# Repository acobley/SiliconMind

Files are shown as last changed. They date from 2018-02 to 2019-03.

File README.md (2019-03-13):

View this project on [CADLAB.io](https://cadlab.io/node/794). 

# SiliconMind
PCB3 is a test release.  
**Do not use** . Unwired airwire on PCB.
Use the hardware files

Pure Keys aec-pcb3.sch
Pure Keys aec-pcb3.brd

PCB2 is a working release.  Use the hardware files

Pure Keys aec-pcb2.sch
Pure Keys aec-pcb2.brd

**make sure that the 20 way header(keyboard connector) is soldered on so the connector is on the otherside of the board to the components. **

**Button 1** controls the mode. Starts in Polyphonc mode.  
Press once (2 flashes) for split mode.  CV1/Trig1 is lower half of keyboard. CV2/Trig2 is upper
Press again (3 flashes for mono mode.  CV1/Trig 1 only
Press again (1 flash) to return to poly mode.

**Button 2* is record/play mode
Press and hold (button flashes when ready) to enter record mode.  The note on each trig in will be recorded (up to 64), the note length is **not** recorded.  When finished press once to exit record mode.   Press once (quickly) to enter play mode.

For step type recording use a manual trigger press.

**Note** Will only record the bottom note, best used in Mono mode for recording.   In playback mode will output on CV1/Trig1 and other notes are shifted up one.  In Split mode upper half of keyboard is available.

**Glide** 
Controls the Portamento rate.  Works in Mono/Poly mode.  In Split mode only upper half of keyboard is glided.

-------------------------------------------------------------------

This is a project to create a voltage control keyboard for Eurorack Synths.  The aim is to create a fourvoice polyphtonic keyboard, with no MIDI at all.

The hardware is based around the ATMEGA.

See alos Changelog.txt in Hardware

Software 

SiliconMind.ion is latest for aec-pcb2 First PCB hardware

                  Work in progress, in test !

Hardware Designs:

Pure Keys aec Original Design

Pure Keys aec-pcb1 First PCB  do not use

      	       Needs pull down resistors on	MK lines
                   5V Ref needs	 replacing with 3v version
                   Switch needs	 pull up, not down.
Pure Keys aec-pcb2. 

                   Changes in pcb1 are rolled into this
                   Pure Keys aec-pcb2 In Progress

Pure Keys aec-pcb3-inProgress (obsolete)

	Next design in progress
	     	    Changes from pcb2 are rolled into this 
		    
Pure Keys aec-pcb3-smd-inProgress 

	SMD version.   Next design in progress
	     	    Changes from pcb2 are rolled into this 
Pure Keys aec-pcb3 

	SMD version.   **Do not use** Unwired airwire on PCB.
	
	     	    Changes from pcb2 are rolled into this

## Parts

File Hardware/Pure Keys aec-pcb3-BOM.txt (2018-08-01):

"Part";"Value";"Device";"Package";"Description";"MF";"MPN";"OC_FARNELL";"OC_NEWARK";"PACKAGE";"PROD_ID";"RC-PART";"RS-PART";"SUPPLIER";"VALUE";
"74151-1";"74S151D";"74S151D";"SO16";"Data SELECTOR/MULTIPLEXER";"";"";"";"";"";"";"";"436-7436";"";"";
"74238";"74HC238DN";"74HC238DN";"SO16";"1 of 8 noninverting DECODER/DEMULTIPLEXER";"";"";"";"";"";"";"";"483-6487 (10off)";"";"";
"75151-2";"74S151D";"74S151D";"SO16";"Data SELECTOR/MULTIPLEXER";"";"";"";"";"";"";"";"436-7436";"";"";
"BUT1";"PB6149L-5";"PB6149L-5";"PB6149L";"";"";"";"";"";"";"";"";"";"";"";
"BUT2";"PB6149L-5";"PB6149L-5";"PB6149L";"";"";"";"";"";"";"";"";"";"";"";
"BUT3";"PB6149L-5";"PB6149L-5";"PB6149L";"";"";"";"";"";"";"";"";"";"";"";
"C3";"100n";"C-USC0805K";"C0805K";"CAPACITOR, American symbol";"";"";"";"";"";"";"";"";"";"";
"C4";"10u";"CPOL-US153CLV-0505";"153CLV-0505";"POLARIZED CAPACITOR, American symbol";"";"";"";"";"";"";"";"";"";"";
"C5";"100n";"C-USC0805K";"C0805K";"CAPACITOR, American symbol";"";"";"";"";"";"";"";"";"";"";
"C6";"10u";"C-USC0805K";"C0805K";"CAPACITOR, American symbol";"";"";"";"";"";"";"";"";"";"";
"C7";"10u";"C-USC0805K";"C0805K";"CAPACITOR, American symbol";"";"";"";"";"";"";"";"";"";"";
"C8";"100n";"C-USC0805K";"C0805K";"CAPACITOR, American symbol";"";"";"";"";"";"";"";"";"";"";
"C9";"100n";"C-USC0805K";"C0805K";"CAPACITOR, American symbol";"";"";"";"";"";"";"";"";"";"";
"C10";"100n";"C-USC0805K";"C0805K";"CAPACITOR, American symbol";"";"";"";"";"";"";"";"";"";"";
"C11";"100n";"C-USC0805K";"C0805K";"CAPACITOR, American symbol";"";"";"";"";"";"";"";"";"";"";
"C12";"100n";"C-USC0805K";"C0805K";"CAPACITOR, American symbol";"";"";"";"";"";"";"";"";"";"";
"C13";"100n";"C-USC0805K";"C0805K";"CAPACITOR, American symbol";"";"";"";"";"";"";"";"";"";"";
"C14";"100n";"C-USC0805K";"C0805K";"CAPACITOR, American symbol";"";"";"";"";"";"";"";"";"";"";
"C17";"22p";"C-USC0805K";"C0805K";"CAPACITOR, American symbol";"";"";"";"";"";"";"";"";"";"";
"C18";"22p";"C-USC0805K";"C0805K";"CAPACITOR, American symbol";"";"";"";"";"";"";"";"";"";"";
"CLK_IN";"S_JACK";"S_JACK";"S_JACK";"";"";"";"";"";"";"";"";"";"";"";
"CLOCK";"2N3904";"TRANSISTOR_MMBT3904";"TRANSISTOR_SINGLE_N-TYPE";"";"";"";"";"";"";"";"";"725-8616 ";"";"";
"CV1";"S_JACK";"S_JACK";"S_JACK";"";"";"";"";"";"";"";"";"";"";"";
"CV2";"S_JACK";"S_JACK";"S_JACK";"";"";"";"";"";"";"";"";"";"";"";
"CV3";"S_JACK";"S_JACK";"S_JACK";"";"";"";"";"";"";"";"";"";"";"";
"CV4";"S_JACK";"S_JACK";"S_JACK";"";"";"";"";"";"";"";"";"";"";"";
"GATE";"rate";"9MMPOT";"POT";"";"";"";"";"";"";"";"";"";"";"";
"GLIDE1";"rate";"9MMPOT";"POT";"";"";"";"";"";"";"";"";"";"";"";
"INVERTOR";"74AC04D";"74AC04D";"SO14";"Hex INVERTER";"";"";"";"";"";"";"171-3461 (50 off)";"";"";"";
"ISP1";"AVRISP-6";"AVRISP-6";"AVRISP";"AVR ISP HEADER";"";"";"";"";"";"";"";"";"";"";
"JP2";"USB-B";"USBPTH";"USB-B-PTH";"USB Connectors";"";"";"";"";"";"CONN-08278";"";"";"";"USB-B";
"MCP4922";"MCP4922MCP4922-SO14";"MCP4922MCP4922-SO14";"SO14";"";"";"";"";"";"";"";"";"402-910 ";"";"";
"MCP4922-2";"MCP4922MCP4922-SO14";"MCP4922MCP4922-SO14";"SO14";"";"";"";"";"";"";"";"";"";"";"";
"MCP6004-TRIG";"MCP6004D";"MCP6004D";"SO14";"OP AMP";"";"";"";"";"";"";"";"628-3481 (10)";"";"";
"MCP6004-V";"MCP6004D";"MCP6004D";"SO14";"OP AMP";"";"";"";"";"";"";"";"628-3481 (10)";"";"";
"Q2";"20MHz";"CRYSTALHC49UP";"HC49UP";"CRYSTAL";"";"";"unknown";"unknown";"";"";"";"";"";"";
"R1";"1K";"R-US_R0805";"R0805";"RESISTOR, American symbol";"";"";"";"";"";"";"";"223-0427";"";"";
"R2";"330R";"R-US_R0805";"R0805";"RESISTOR, American symbol";"";"";"";"";"";"";"";"";"";"";
"R3";"2K";"R-US_R0805";"R0805";"RESISTOR, American symbol";"";"";"";"";"";"";"";"";"";"";
"R5";"10K";"R-US_R0805";"R0805";"RESISTOR, American symbol";"";"";"";"";"";"";"";"";"";"";
"R6";"100K";"R-US_R0805";"R0805";"RESISTOR, American symbol";"";"";"";"";"";"";"";"";"";"";
"R7";"1M";"R-US_R0805";"R0805";"RESISTOR, American symbol";"";"";"";"";"";"";"";"";"";"";
"R8";"100K";"R-US_R0805";"R0805";"RESISTOR, American symbol";"";"";"";"";"";"";"";"";"";"";
"R9";"100K";"R-US_R0805";"R0805";"RESISTOR, American symbol";"";"";"";"";"";"";"";"";"";"";
"R10";"1K";"R-US_R0805";"R0805";"RESISTOR, American symbol";"";"";"";"";"";"";"";"223-0427";"";"";
"R11";"1K";"R-US_R0805";"R0805";"RESISTOR, American symbol";"";"";"";"";"";"";"";"223-0427";"";"";
"R12";"1K";"R-US_R0805";"R0805";"RESISTOR, American symbol";"";"";"";"";"";"";"";"223-0427";"";"";
"R13";"1K";"R-US_R0805";"R0805";"RESISTOR, American symbol";"";"";"";"";"";"";"";"223-0427";"";"";
"R14";"330R";"R-US_R0805";"R0805";"RESISTOR, American symbol";"";"";"";"";"";"";"";"";"";"";
"R15";"10K";"R-US_R0805";"R0805";"RESISTOR, American symbol";"";"";"";"";"";"";"";"";"";"";
"R16";"10K";"R-US_R0805";"R0805";"RESISTOR, American symbol";"";"";"";"";"";"";"";"";"";"";
"R17";"10K";"R-US_R0805";"R0805";"RESISTOR, American symbol";"";"";"";"";"";"";"";"";"";"";
"R18";"10K";"R-US_R0805";"R0805";"RESISTOR, American symbol";"";"";"";"";"";"";"";"";"";"";
"R19";"10K";"R-US_R0805";"R0805";"RESISTOR, American symbol";"";"";"";"";"";"";"";"";"";"";
"R20";"10K";"R-US_R0805";"R0805";"RESISTOR, American symbol";"";"";"";"";"";"";"";"";"";"";
"R21";"10K";"R-US_R0805";"R0805";"RESISTOR, American symbol";"";"";"";"";"";"";"";"";"";"";
"R22";"10K";"R-US_R0805";"R0805";"RESISTOR, American symbol";"";"";"";"";"";"";"";"";"";"";
"R23";"100K";"R-US_R0805";"R0805";"RESISTOR, American symbol";"";"";"";"";"";"";"";"";"";"";
"R24";"1K";"R-US_R0805";"R0805";"RESISTOR, American symbol";"";"";"";"";"";"";"";"223-0427";"";"";
"R25";"1K";"R-US_R0805";"R0805";"RESISTOR, American symbol";"";"";"";"";"";"";"";"223-0427";"";"";
"R26";"1K";"R-US_R0805";"R0805";"RESISTOR, American symbol";"";"";"";"";"";"";"";"223-0427";"";"";
"R27";"1K";"R-US_R0805";"R0805";"RESISTOR, American symbol";"";"";"";"";"";"";"";"223-0427";"";"";
"R28";"1K";"R-US_R0805";"R0805";"RESISTOR, American symbol";"";"";"";"";"";"";"";"223-0427";"";"";
"R29";"10K";"R-US_R0805";"R0805";"RESISTOR, American symbol";"";"";"";"";"";"";"";"";"";"";
"R56";"330R";"R-US_R0805";"R0805";"RESISTOR, American symbol";"";"";"";"";"";"";"";"";"";"";
"REF";"LM4040";"LM4040A30IDBZT";"SOT95P237X112-3N";"PRECISION MICROPOWER SHUNT VOLTAGE REFERENCE";"";"LM4040A30IDBZT";"1755108";"58K5870";"3-SOT-23";"";"";"809-6343";"TEXAS INSTRUMENTS";"";
"TRIG1";"S_JACK";"S_JACK";"S_JACK";"";"";"";"";"";"";"";"";"";"";"";
"TRIG2";"S_JACK";"S_JACK";"S_JACK";"";"";"";"";"";"";"";"";"";"";"";
"TRIG3";"S_JACK";"S_JACK";"S_JACK";"";"";"";"";"";"";"";"";"";"";"";
"TRIG4";"S_JACK";"S_JACK";"S_JACK";"";"";"";"";"";"";"";"";"";"";"";
"U$4";"KeyBoard Connector";"CONN_10X2";"2X10";"Multi connection point. Often used as Generic Header-pin footprint for 0.1 inch spaced/style header connections";"";"";"";"";"";"";"";"669-5364";"";"";
"U1";"ATMEGA328P_TQFP";"ATMEGA328P_TQFP";"TQFP32-08";"Popular 328P in QFP";"";"";"";"";"";"IC-09069";"";"131-0271";"";"ATMEGA328P_TQFP";

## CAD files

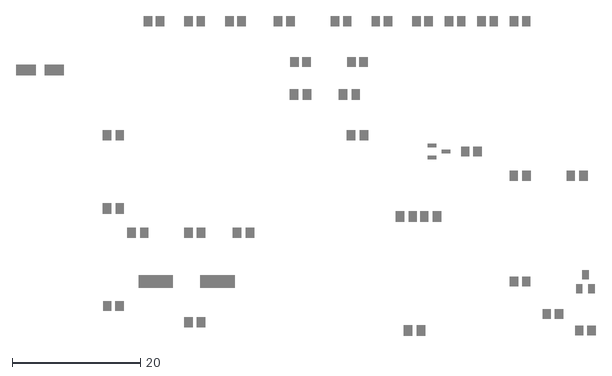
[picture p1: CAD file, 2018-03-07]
Hardware/Pure Keys aec-pcb1.dxf
90.4 x 49.8

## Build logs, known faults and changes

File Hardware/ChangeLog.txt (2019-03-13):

Pure Keys - Design from GMSN
Pure Keys AEC First design from AEC
PureKeys aec-pcb1   AEC design First board ordered Order ID G136226 10/2/2018
PureKeys aec-pcb2   AEC design board ordered Order ID G145482 21/3/2018
PureKeys aec-pcb3   AEC SMD design Board Ordered Order ID G180605 30/7/2018

PureKeys aec-pcb3 AEC
------------------------------------------------
Airwire between T7 and 74238

PureKeys aec-pcb3-smd inProgress AEC
------------------------------------------------
Changed over to SMD components
Add second 74151 for velocity detection

15/3/2018  Changed 74238 to 74138
20/3/2018  Changed back to L74238

PureKeys aec-pcb2-inProgress AEC 
------------------------------------------------

aec-pcb2-inProgress Change Log 
4/3/2018 Removed reference to TL072 IC2 
13/3/2018  ChangedTL074 for MCP6004.  The TL series needs +/- VDD
15/3/2018  Changed 74238 to 74138
16/3/2018  Move switch resistors to 5v end
20/3/2018  Changed to 3V reference and changed the ref resistor R3 to 2K
20/3/2018  Changed back to L74238
20/3/2018  pull down 1K on MK0-Mk4

PureKeys aec-pcb3-inProgress AEC Current design in progress 
------------------------------------------------

29/7/2018 Move to SMD IC's
29/7/2018 Changed to vertical sockets.

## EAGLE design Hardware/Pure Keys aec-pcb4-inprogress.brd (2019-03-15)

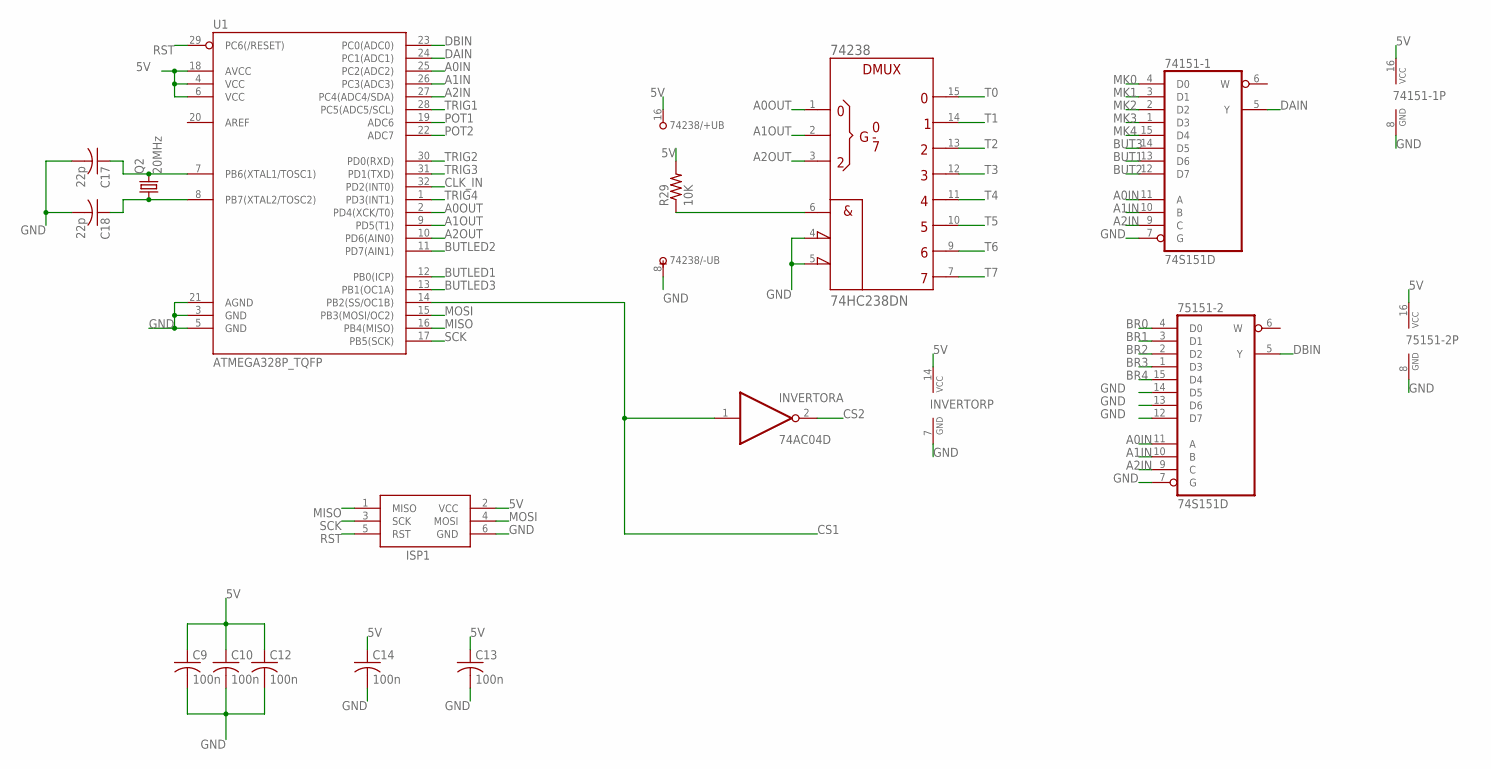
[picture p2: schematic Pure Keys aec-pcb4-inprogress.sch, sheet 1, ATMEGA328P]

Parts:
74151-1, 75151-2: 74S151D; SO16
74238: 74HC238DN; SO16
C9, C10, C12, C13, C14: 100n; C0805K
C17, C18: 22p; C0805K
INVERTOR: 74AC04D; SO14
ISP1: AVRISP-6; AVRISP
Q2: 20MHz; HC49UP
R29: 10K; R0805
U1: ATMEGA328P_TQFP; TQFP32-08

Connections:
5V: 74151-1.16 (VCC), 74238.16 (+UB), 75151-2.16 (VCC), C9.1, C10.1, C12.1, C13.1, C14.1, INVERTOR.14 (VCC), ISP1.2 (VCC), R29.2, U1.4 (VCC), U1.6 (VCC), U1.18 (AVCC); also elsewhere on the board
A0IN: 74151-1.11 (A), 75151-2.11 (A), U1.25 (PC2(ADC2))
A0OUT: 74238.1 (A), U1.2 (PD4(XCK/T0))
A1IN: 74151-1.10 (B), 75151-2.10 (B), U1.26 (PC3(ADC3))
A1OUT: 74238.2 (B), U1.9 (PD5(T1))
A2IN: 74151-1.9 (C), 75151-2.9 (C), U1.27 (PC4(ADC4/SDA))
A2OUT: 74238.3 (C), U1.10 (PD6(AIN0))
BR0: 75151-2.4 (D0); also elsewhere on the board
BR1: 75151-2.3 (D1); also elsewhere on the board
BR2: 75151-2.2 (D2); also elsewhere on the board
BR3: 75151-2.1 (D3); also elsewhere on the board
BR4: 75151-2.15 (D4); also elsewhere on the board
BUT1: 74151-1.13 (D6); also elsewhere on the board
BUT2: 74151-1.12 (D7); also elsewhere on the board
BUT3: 74151-1.14 (D5); also elsewhere on the board
BUTLED1: U1.12 (PB0(ICP)); also elsewhere on the board
BUTLED2: U1.11 (PD7(AIN1)); also elsewhere on the board
BUTLED3: U1.13 (PB1(OC1A)); also elsewhere on the board
CLK_IN: U1.32 (PD2(INT0)); also elsewhere on the board
CS1: INVERTOR.1 (I), U1.14 (PB2(SS/OC1B)); also elsewhere on the board
CS2: INVERTOR.2 (O); also elsewhere on the board
DAIN: 74151-1.5 (Y), U1.24 (PC1(ADC1))
DBIN: 75151-2.5 (Y), U1.23 (PC0(ADC0))
ENOUT1: 74238.6 (G1), R29.1
GND: 74151-1.7 (G), 74151-1.8 (GND), 74238.4 (!G2A), 74238.5 (!G2B), 74238.8 (-UB), 75151-2.7 (G), 75151-2.8 (GND), 75151-2.12 (D7), 75151-2.13 (D6), 75151-2.14 (D5), C9.2, C10.2, C12.2, C13.2, C14.2, C17.2, C18.2, INVERTOR.7 (GND), ISP1.6 (GND), U1.3 (GND), U1.5 (GND), U1.21 (AGND); also elsewhere on the board
MISO: ISP1.1 (MISO), U1.16 (PB4(MISO))
MK0: 74151-1.4 (D0); also elsewhere on the board
MK1: 74151-1.3 (D1); also elsewhere on the board
MK2: 74151-1.2 (D2); also elsewhere on the board
MK3: 74151-1.1 (D3); also elsewhere on the board
MK4: 74151-1.15 (D4); also elsewhere on the board
MOSI: ISP1.4 (MOSI), U1.15 (PB3(MOSI/OC2)); also elsewhere on the board
unnamed: C17.1, Q2.2, U1.7 (PB6(XTAL1/TOSC1))
unnamed: C18.1, Q2.1, U1.8 (PB7(XTAL2/TOSC2))
POT1: U1.19 (ADC6); also elsewhere on the board
POT2: U1.22 (ADC7); also elsewhere on the board
RST: ISP1.5 (RST), U1.29 (PC6(/RESET))
SCK: ISP1.3 (SCK), U1.17 (PB5(SCK)); also elsewhere on the board
T0: 74238.15 (Y0); also elsewhere on the board
T1: 74238.14 (Y1); also elsewhere on the board
T2: 74238.13 (Y2); also elsewhere on the board
T3: 74238.12 (Y3); also elsewhere on the board
T4: 74238.11 (Y4); also elsewhere on the board
T5: 74238.10 (Y5); also elsewhere on the board
T6: 74238.9 (Y6); also elsewhere on the board
T7: 74238.7 (Y7); also elsewhere on the board
TRIG1: U1.28 (PC5(ADC5/SCL)); also elsewhere on the board
TRIG2: U1.30 (PD0(RXD)); also elsewhere on the board
TRIG3: U1.31 (PD1(TXD)); also elsewhere on the board
TRIG4: U1.1 (PD3(INT1)); also elsewhere on the board

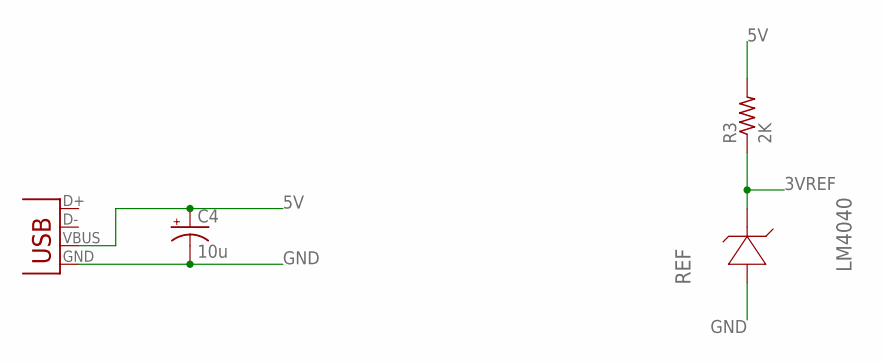
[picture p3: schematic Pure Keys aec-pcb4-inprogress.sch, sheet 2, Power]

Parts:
C4: 10u; 153CLV-0505
JP2: USB-B; USB-B-PTH
R3: 2K; R0805
REF: LM4040; SOT95P237X112-3N; MPN LM4040A30IDBZT

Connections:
3VREF: R3.1, REF.1 (CATHODE); also elsewhere on the board
5V: C4.+, JP2.VBUS, R3.2; also elsewhere on the board
GND: C4.-, JP2.GND, REF.2 (ANODE); also elsewhere on the board

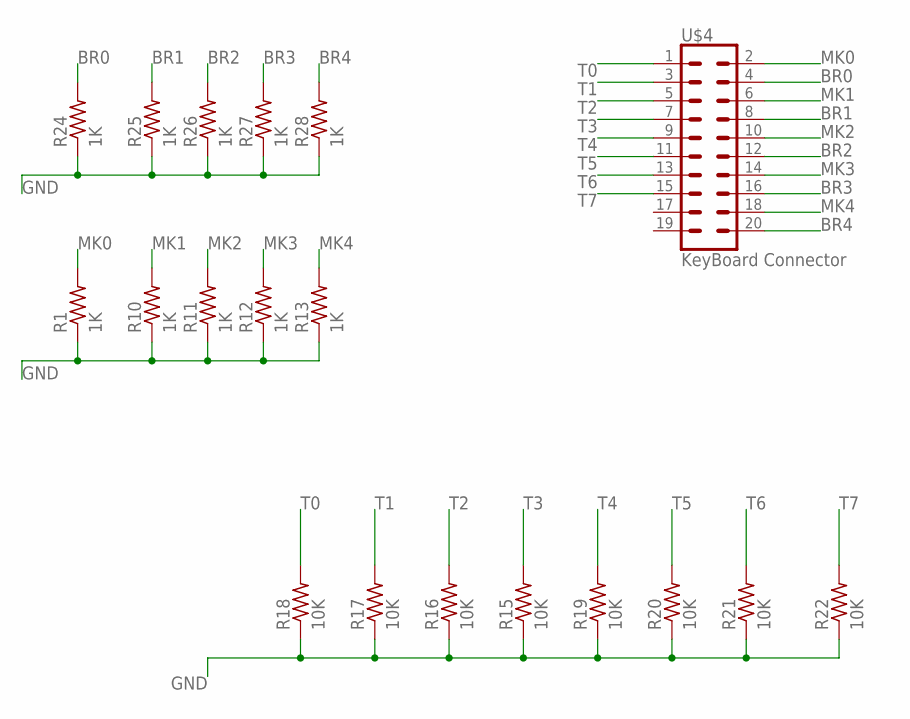
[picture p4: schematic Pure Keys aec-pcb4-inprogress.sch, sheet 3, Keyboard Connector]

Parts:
R1, R10, R11, R12, R13, R24, R25, R26, R27, R28: 1K; R0805
R15, R16, R17, R18, R19, R20, R21, R22: 10K; R0805
U$4: KeyBoard Connector; 2X10

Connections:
BR0: R24.2, U$4.4; also elsewhere on the board
BR1: R25.2, U$4.8; also elsewhere on the board
BR2: R26.2, U$4.12; also elsewhere on the board
BR3: R27.2, U$4.16; also elsewhere on the board
BR4: R28.2, U$4.20; also elsewhere on the board
GND: R1.1, R10.1, R11.1, R12.1, R13.1, R15.1, R16.1, R17.1, R18.1, R19.1, R20.1, R21.1, R22.1, R24.1, R25.1, R26.1, R27.1, R28.1; also elsewhere on the board
MK0: R1.2, U$4.2; also elsewhere on the board
MK1: R10.2, U$4.6; also elsewhere on the board
MK2: R11.2, U$4.10; also elsewhere on the board
MK3: R12.2, U$4.14; also elsewhere on the board
MK4: R13.2, U$4.18; also elsewhere on the board
T0: R18.2, U$4.1; also elsewhere on the board
T1: R17.2, U$4.3; also elsewhere on the board
T2: R16.2, U$4.5; also elsewhere on the board
T3: R15.2, U$4.7; also elsewhere on the board
T4: R19.2, U$4.9; also elsewhere on the board
T5: R20.2, U$4.11; also elsewhere on the board
T6: R21.2, U$4.13; also elsewhere on the board
T7: R22.2, U$4.15; also elsewhere on the board

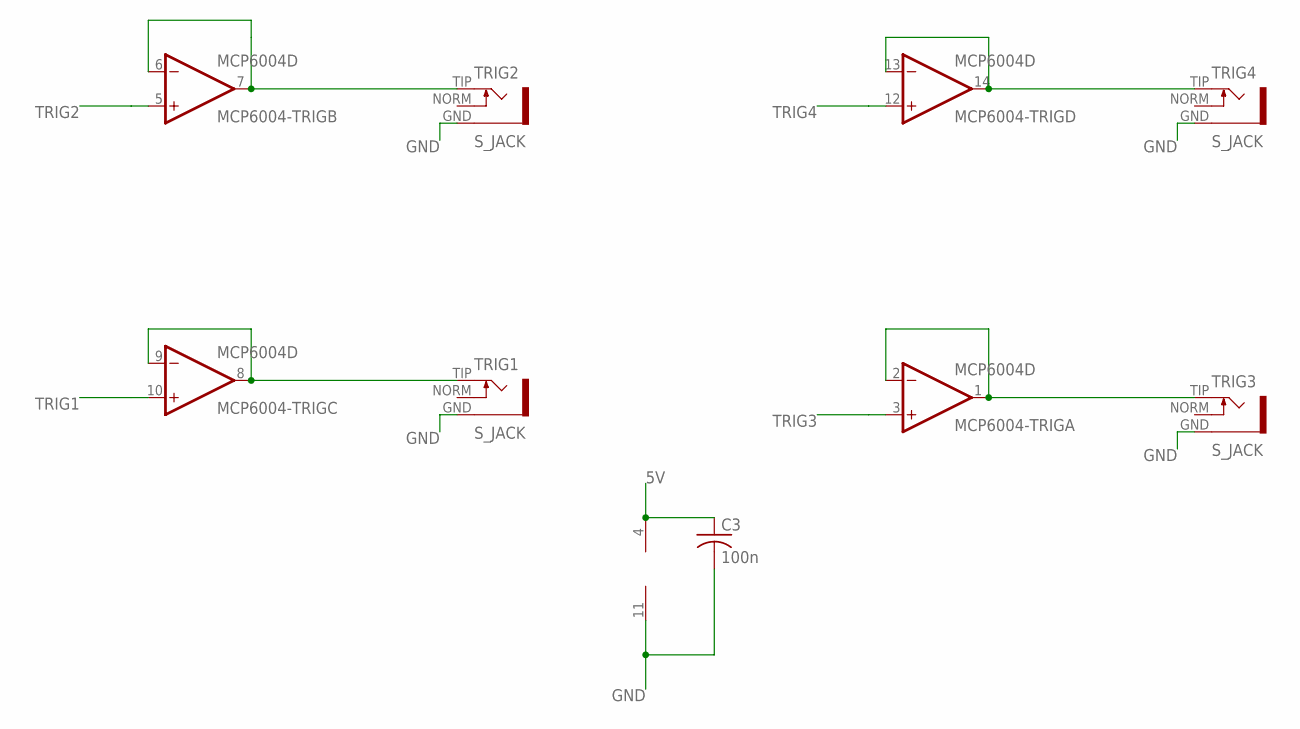
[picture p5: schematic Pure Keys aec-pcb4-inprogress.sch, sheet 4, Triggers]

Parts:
C3: 100n; C0805K
MCP6004-TRIG: MCP6004D; SO14
TRIG1, TRIG2, TRIG3, TRIG4: S_JACK

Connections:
5V: C3.1, MCP6004-TRIG.4 (V+); also elsewhere on the board
GND: C3.2, MCP6004-TRIG.11 (V-), TRIG1.GND, TRIG2.GND, TRIG3.GND, TRIG4.GND; also elsewhere on the board
unnamed: MCP6004-TRIG.6 (-IN), MCP6004-TRIG.7 (OUT), TRIG2.TIP
unnamed: MCP6004-TRIG.8 (OUT), MCP6004-TRIG.9 (-IN), TRIG1.TIP
unnamed: MCP6004-TRIG.13 (-IN), MCP6004-TRIG.14 (OUT), TRIG4.TIP
unnamed: MCP6004-TRIG.1 (OUT), MCP6004-TRIG.2 (-IN), TRIG3.TIP
TRIG1: MCP6004-TRIG.10 (+IN); also elsewhere on the board
TRIG2: MCP6004-TRIG.5 (+IN); also elsewhere on the board
TRIG3: MCP6004-TRIG.3 (+IN); also elsewhere on the board
TRIG4: MCP6004-TRIG.12 (+IN); also elsewhere on the board

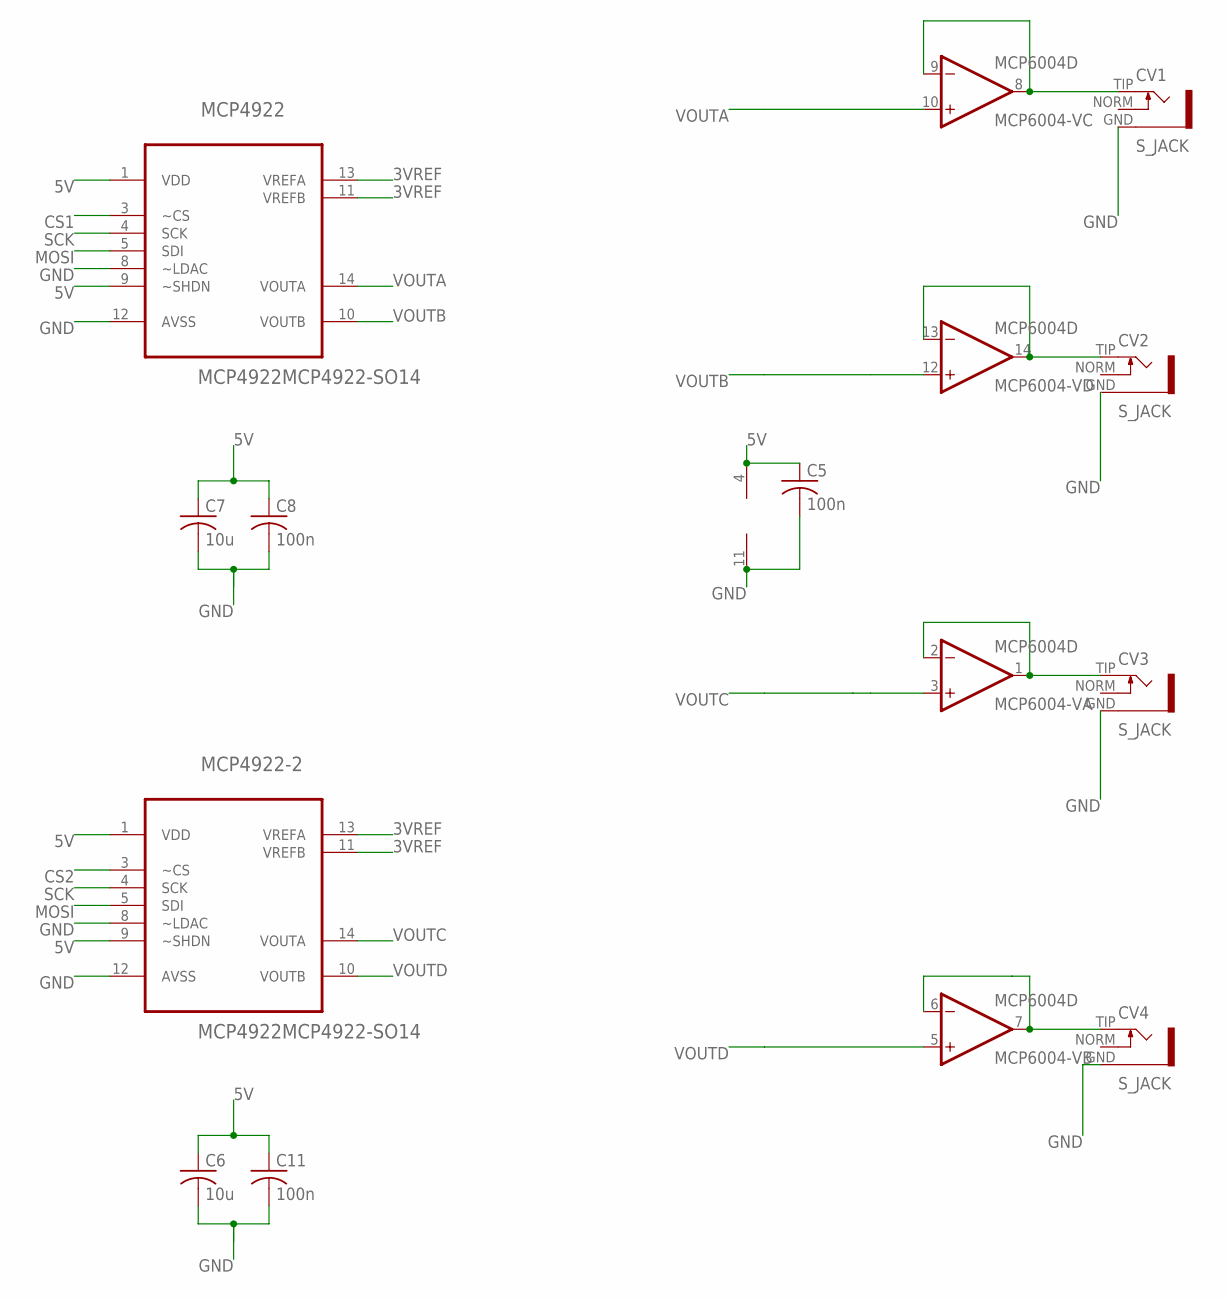
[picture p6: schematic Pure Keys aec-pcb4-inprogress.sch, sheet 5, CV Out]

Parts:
C5, C8, C11: 100n; C0805K
C6, C7: 10u; C0805K
CV1, CV2, CV3, CV4: S_JACK
MCP4922, MCP4922-2: MCP4922MCP4922-SO14; SO14
MCP6004-V: MCP6004D; SO14

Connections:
3VREF: MCP4922.11 (VREFB), MCP4922.13 (VREFA), MCP4922-2.11 (VREFB), MCP4922-2.13 (VREFA); also elsewhere on the board
5V: C5.1, C6.1, C7.1, C8.1, C11.1, MCP4922.1 (VDD), MCP4922.9 (~SHDN), MCP4922-2.1 (VDD), MCP4922-2.9 (~SHDN), MCP6004-V.4 (V+); also elsewhere on the board
CS1: MCP4922.3 (~CS); also elsewhere on the board
CS2: MCP4922-2.3 (~CS); also elsewhere on the board
GND: C5.2, C6.2, C7.2, C8.2, C11.2, CV1.GND, CV2.GND, CV3.GND, CV4.GND, MCP4922.8 (~LDAC), MCP4922.12 (AVSS), MCP4922-2.8 (~LDAC), MCP4922-2.12 (AVSS), MCP6004-V.11 (V-); also elsewhere on the board
MOSI: MCP4922.5 (SDI), MCP4922-2.5 (SDI); also elsewhere on the board
unnamed: CV1.TIP, MCP6004-V.8 (OUT), MCP6004-V.9 (-IN)
unnamed: CV4.TIP, MCP6004-V.6 (-IN), MCP6004-V.7 (OUT)
unnamed: CV3.TIP, MCP6004-V.1 (OUT), MCP6004-V.2 (-IN)
unnamed: CV2.TIP, MCP6004-V.13 (-IN), MCP6004-V.14 (OUT)
SCK: MCP4922.4 (SCK), MCP4922-2.4 (SCK); also elsewhere on the board
VOUTA: MCP4922.14 (VOUTA), MCP6004-V.10 (+IN)
VOUTB: MCP4922.10 (VOUTB), MCP6004-V.12 (+IN)
VOUTC: MCP4922-2.14 (VOUTA), MCP6004-V.3 (+IN)
VOUTD: MCP4922-2.10 (VOUTB), MCP6004-V.5 (+IN)

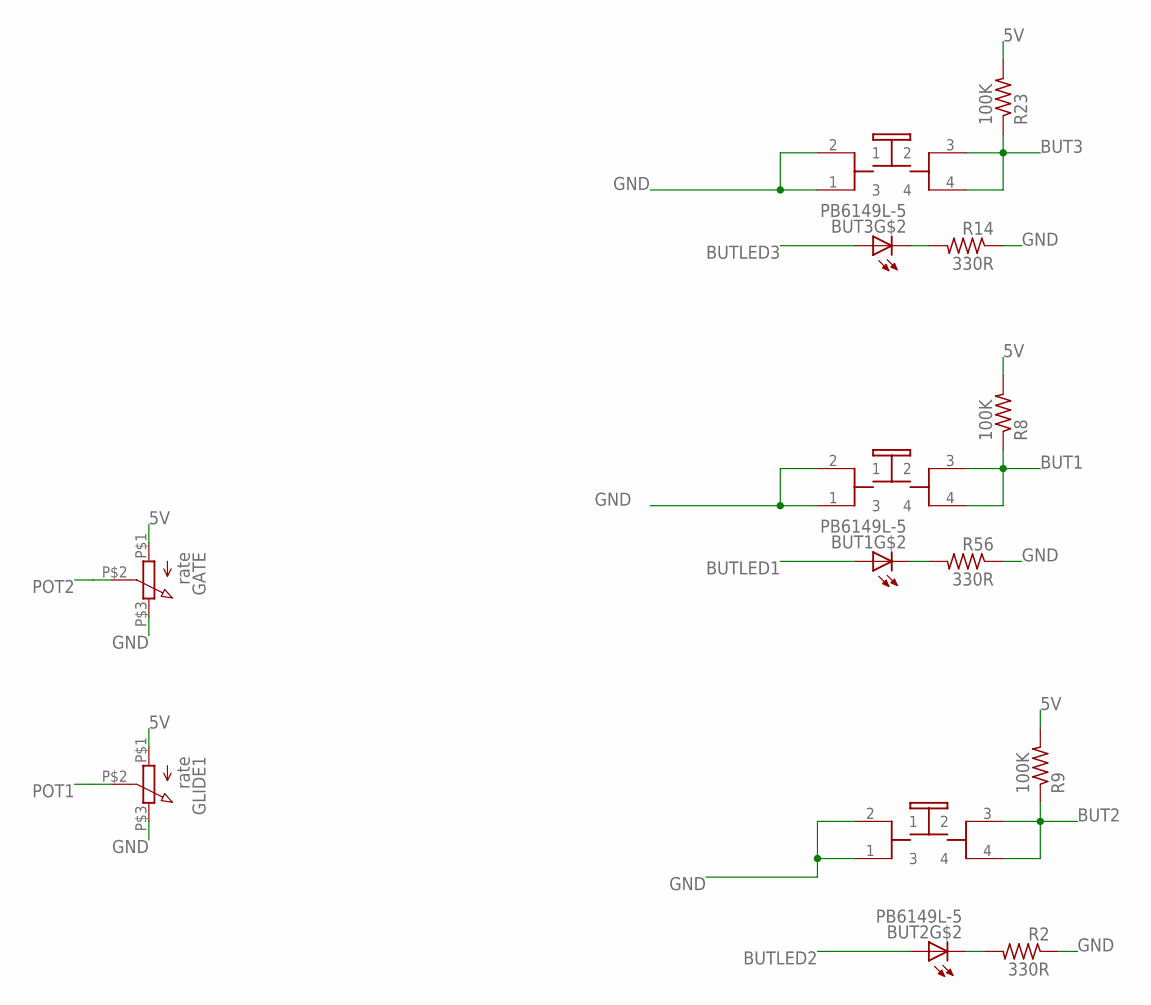
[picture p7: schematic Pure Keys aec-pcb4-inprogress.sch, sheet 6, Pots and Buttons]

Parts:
BUT1, BUT2, BUT3: PB6149L-5; PB6149L
GATE: rate; POT
GLIDE1: rate; POT
R2, R14, R56: 330R; R0805
R8, R9, R23: 100K; R0805

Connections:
5V: GATE.P$1 (1), GLIDE1.P$1 (1), R8.2, R9.2, R23.2; also elsewhere on the board
BUT1: BUT1.3 (2), BUT1.4, R8.1; also elsewhere on the board
BUT2: BUT2.3 (2), BUT2.4, R9.1; also elsewhere on the board
BUT3: BUT3.3 (2), BUT3.4, R23.1; also elsewhere on the board
BUTLED1: BUT1.A; also elsewhere on the board
BUTLED2: BUT2.A; also elsewhere on the board
BUTLED3: BUT3.A; also elsewhere on the board
GND: BUT1.1 (3), BUT1.2 (1), BUT2.1 (3), BUT2.2 (1), BUT3.1 (3), BUT3.2 (1), GATE.P$3 (3), GLIDE1.P$3 (3), R2.1, R14.1, R56.1; also elsewhere on the board
unnamed: BUT3.K (C), R14.2
unnamed: BUT2.K (C), R2.2
unnamed: BUT1.K (C), R56.2
POT1: GLIDE1.P$2 (2); also elsewhere on the board
POT2: GATE.P$2 (2); also elsewhere on the board

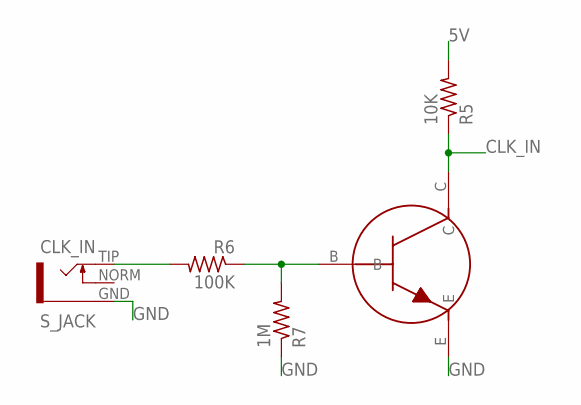
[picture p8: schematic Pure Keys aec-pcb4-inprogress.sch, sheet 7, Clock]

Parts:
CLK_IN: S_JACK
CLOCK: 2N3904; TRANSISTOR_SINGLE_N-TYPE
R5: 10K; R0805
R6: 100K; R0805
R7: 1M; R0805

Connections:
5V: R5.2; also elsewhere on the board
CLK_IN: CLOCK.C, R5.1; also elsewhere on the board
GND: CLK_IN.GND, CLOCK.E, R7.1; also elsewhere on the board
unnamed: CLOCK.B, R6.1, R7.2
unnamed: CLK_IN.TIP, R6.2

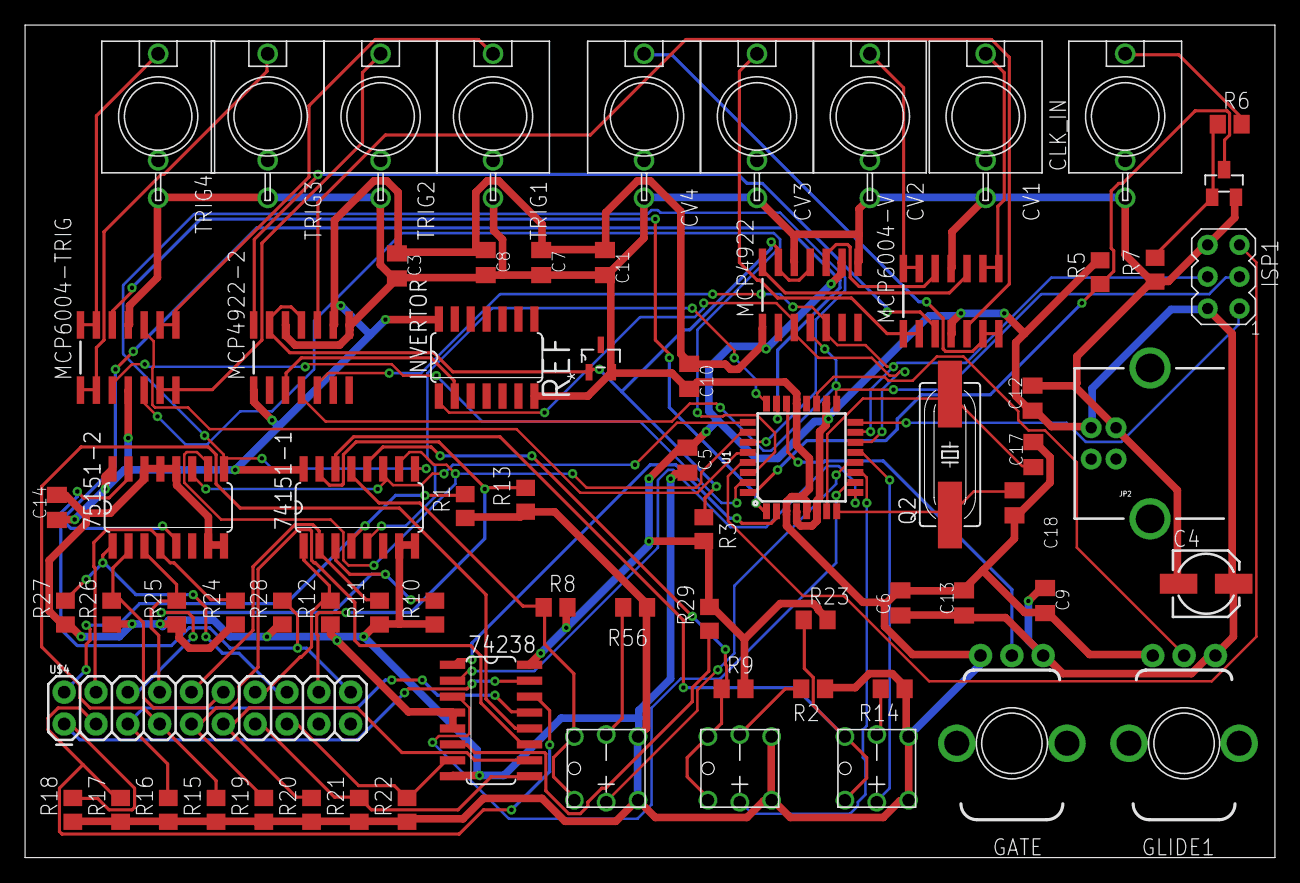
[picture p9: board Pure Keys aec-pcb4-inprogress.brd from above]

Board: 2 copper layers, 99.7 x 66.4 mm, 72 parts (0 on the bottom side), 68 nets.

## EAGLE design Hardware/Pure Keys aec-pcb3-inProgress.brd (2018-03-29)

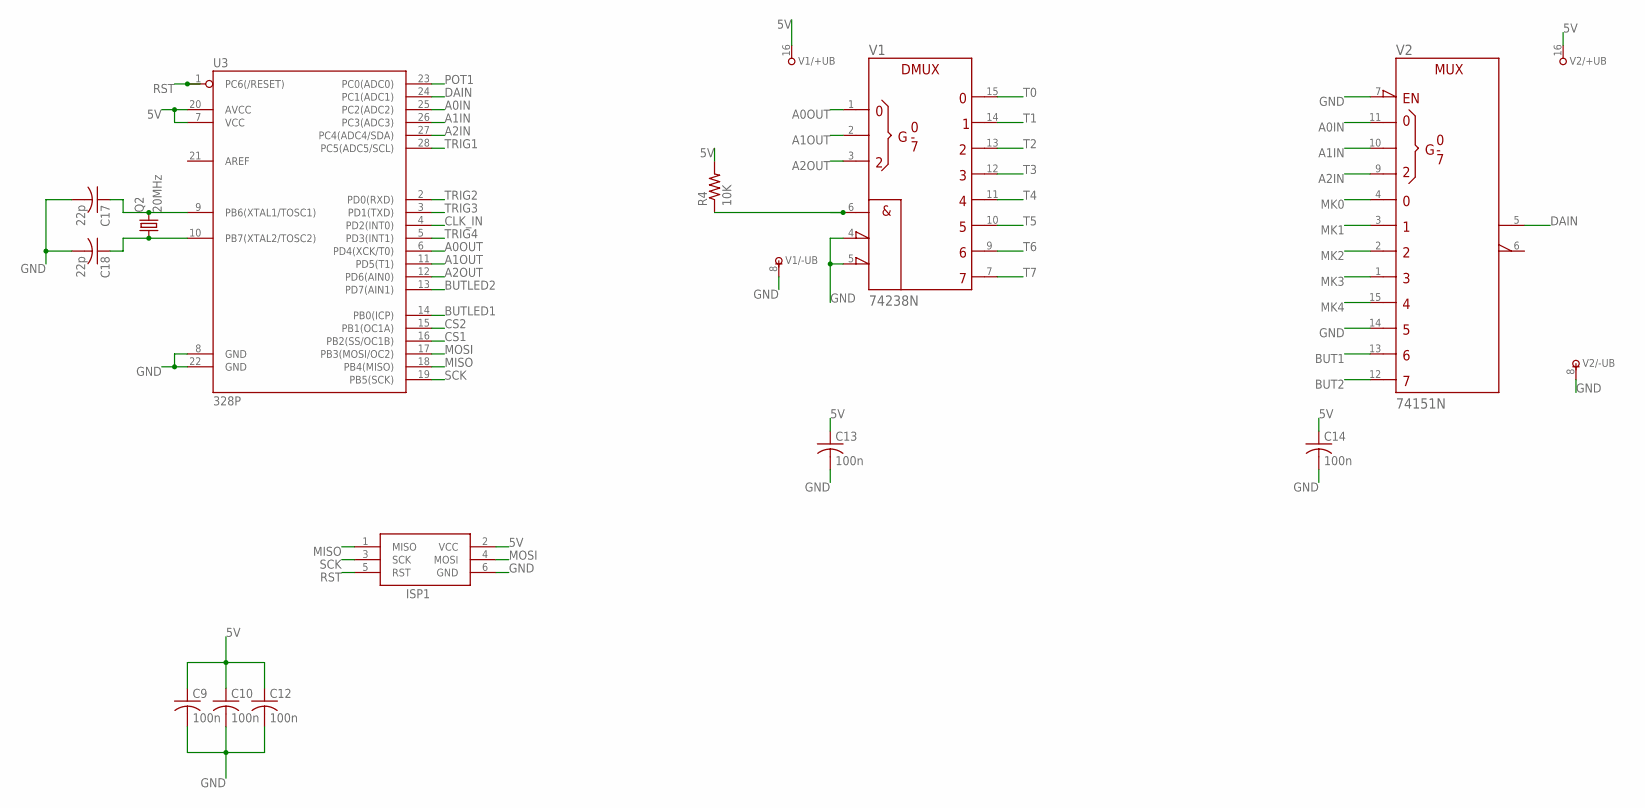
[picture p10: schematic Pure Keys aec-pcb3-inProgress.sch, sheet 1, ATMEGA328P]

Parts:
C9, C10, C12, C13, C14: 100n; C0805K
C17, C18: 22p; C0805K
ISP1: AVRISP-6; AVRISP
Q2: 20MHz; HC49UP
R4: 10K; R0805
U3: 328P; DIP28
V1: 74238N; DIL16
V2: 74151N; DIL16

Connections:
5V: C9.1, C10.1, C12.1, C13.1, C14.1, ISP1.2 (VCC), R4.2, U3.7 (VCC), U3.20 (AVCC), V1.16 (+UB), V2.16 (+UB); also elsewhere on the board
A0IN: U3.25 (PC2(ADC2)), V2.11 (A)
A0OUT: U3.6 (PD4(XCK/T0)), V1.1 (A)
A1IN: U3.26 (PC3(ADC3)), V2.10 (B)
A1OUT: U3.11 (PD5(T1)), V1.2 (B)
A2IN: U3.27 (PC4(ADC4/SDA)), V2.9 (C)
A2OUT: U3.12 (PD6(AIN0)), V1.3 (C)
BUT1: V2.13 (D6); also elsewhere on the board
BUT2: V2.12 (D7); also elsewhere on the board
BUTLED1: U3.14 (PB0(ICP)); also elsewhere on the board
BUTLED2: U3.13 (PD7(AIN1)); also elsewhere on the board
CLK_IN: U3.4 (PD2(INT0)); also elsewhere on the board
CS1: U3.16 (PB2(SS/OC1B)); also elsewhere on the board
CS2: U3.15 (PB1(OC1A)); also elsewhere on the board
DAIN: U3.24 (PC1(ADC1)), V2.5 (Y)
ENOUT: R4.1, V1.6 (G1)
GND: C9.2, C10.2, C12.2, C13.2, C14.2, C17.2, C18.2, ISP1.6 (GND), U3.8 (GND), U3.22 (GND), V1.4 (!G2A), V1.5 (!G2B), V1.8 (-UB), V2.7 (!G), V2.8 (-UB), V2.14 (D5); also elsewhere on the board
MISO: ISP1.1 (MISO), U3.18 (PB4(MISO))
MK0: V2.4 (D0); also elsewhere on the board
MK1: V2.3 (D1); also elsewhere on the board
MK2: V2.2 (D2); also elsewhere on the board
MK3: V2.1 (D3); also elsewhere on the board
MK4: V2.15 (D4); also elsewhere on the board
MOSI: ISP1.4 (MOSI), U3.17 (PB3(MOSI/OC2)); also elsewhere on the board
unnamed: C17.1, Q2.2, U3.9 (PB6(XTAL1/TOSC1))
unnamed: C18.1, Q2.1, U3.10 (PB7(XTAL2/TOSC2))
POT1: U3.23 (PC0(ADC0)); also elsewhere on the board
RST: ISP1.5 (RST), U3.1 (PC6(/RESET))
SCK: ISP1.3 (SCK), U3.19 (PB5(SCK)); also elsewhere on the board
T0: V1.15 (Y0); also elsewhere on the board
T1: V1.14 (Y1); also elsewhere on the board
T2: V1.13 (Y2); also elsewhere on the board
T3: V1.12 (Y3); also elsewhere on the board
T4: V1.11 (Y4); also elsewhere on the board
T5: V1.10 (Y5); also elsewhere on the board
T6: V1.9 (Y6); also elsewhere on the board
T7: V1.7 (Y7); also elsewhere on the board
TRIG1: U3.28 (PC5(ADC5/SCL)); also elsewhere on the board
TRIG2: U3.2 (PD0(RXD)); also elsewhere on the board
TRIG3: U3.3 (PD1(TXD)); also elsewhere on the board
TRIG4: U3.5 (PD3(INT1)); also elsewhere on the board

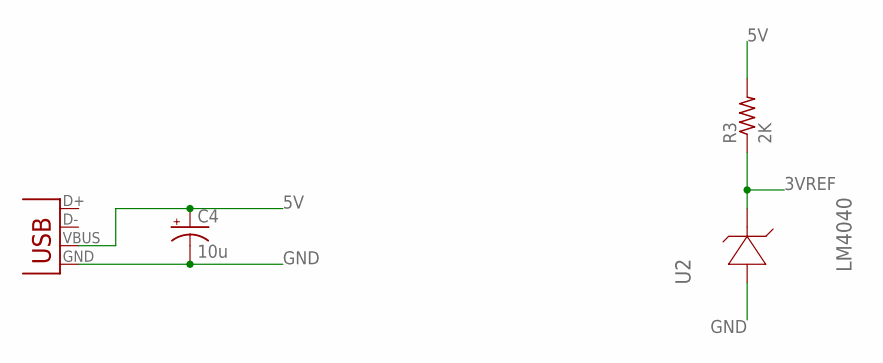
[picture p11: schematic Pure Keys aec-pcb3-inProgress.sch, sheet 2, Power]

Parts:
C4: 10u; 153CLV-0505
JP2: USB-B; USB-B-PTH
R3: 2K; R0805
U2: LM4040; SOT95P237X112-3N; MPN LM4040A30IDBZT

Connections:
3VREF: R3.1, U2.1 (CATHODE); also elsewhere on the board
5V: C4.+, JP2.VBUS, R3.2; also elsewhere on the board
GND: C4.-, JP2.GND, U2.2 (ANODE); also elsewhere on the board

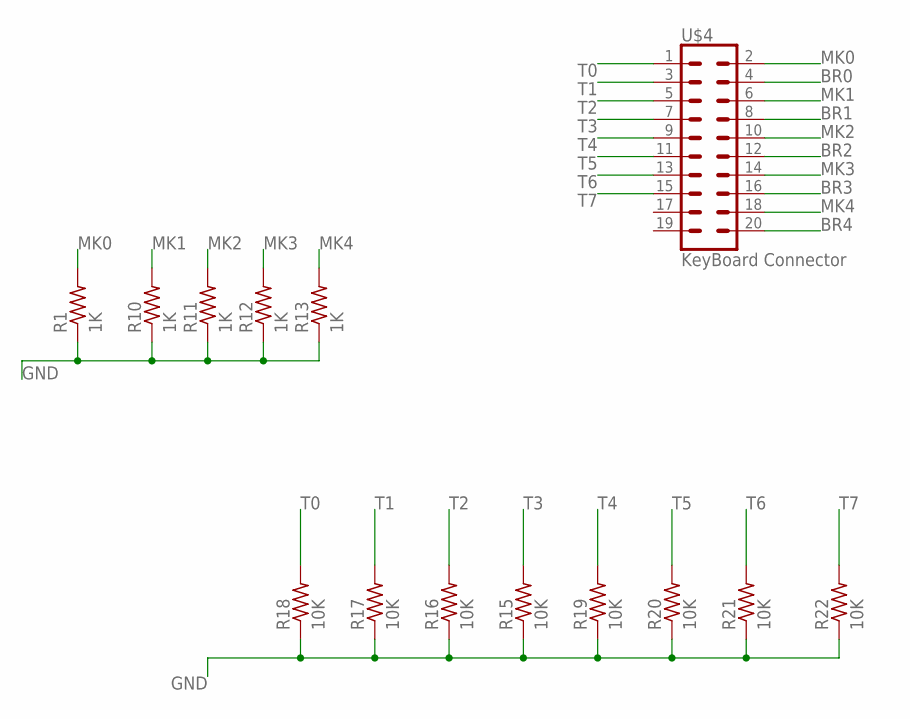
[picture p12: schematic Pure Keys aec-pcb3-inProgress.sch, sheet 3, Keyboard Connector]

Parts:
R1, R10, R11, R12, R13: 1K; R0805
R15, R16, R17, R18, R19, R20, R21, R22: 10K; R0805
U$4: KeyBoard Connector; 2X10

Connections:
BR0: U$4.4
BR1: U$4.8
BR2: U$4.12
BR3: U$4.16
BR4: U$4.20
GND: R1.1, R10.1, R11.1, R12.1, R13.1, R15.1, R16.1, R17.1, R18.1, R19.1, R20.1, R21.1, R22.1; also elsewhere on the board
MK0: R1.2, U$4.2; also elsewhere on the board
MK1: R10.2, U$4.6; also elsewhere on the board
MK2: R11.2, U$4.10; also elsewhere on the board
MK3: R12.2, U$4.14; also elsewhere on the board
MK4: R13.2, U$4.18; also elsewhere on the board
T0: R18.2, U$4.1; also elsewhere on the board
T1: R17.2, U$4.3; also elsewhere on the board
T2: R16.2, U$4.5; also elsewhere on the board
T3: R15.2, U$4.7; also elsewhere on the board
T4: R19.2, U$4.9; also elsewhere on the board
T5: R20.2, U$4.11; also elsewhere on the board
T6: R21.2, U$4.13; also elsewhere on the board
T7: R22.2, U$4.15; also elsewhere on the board

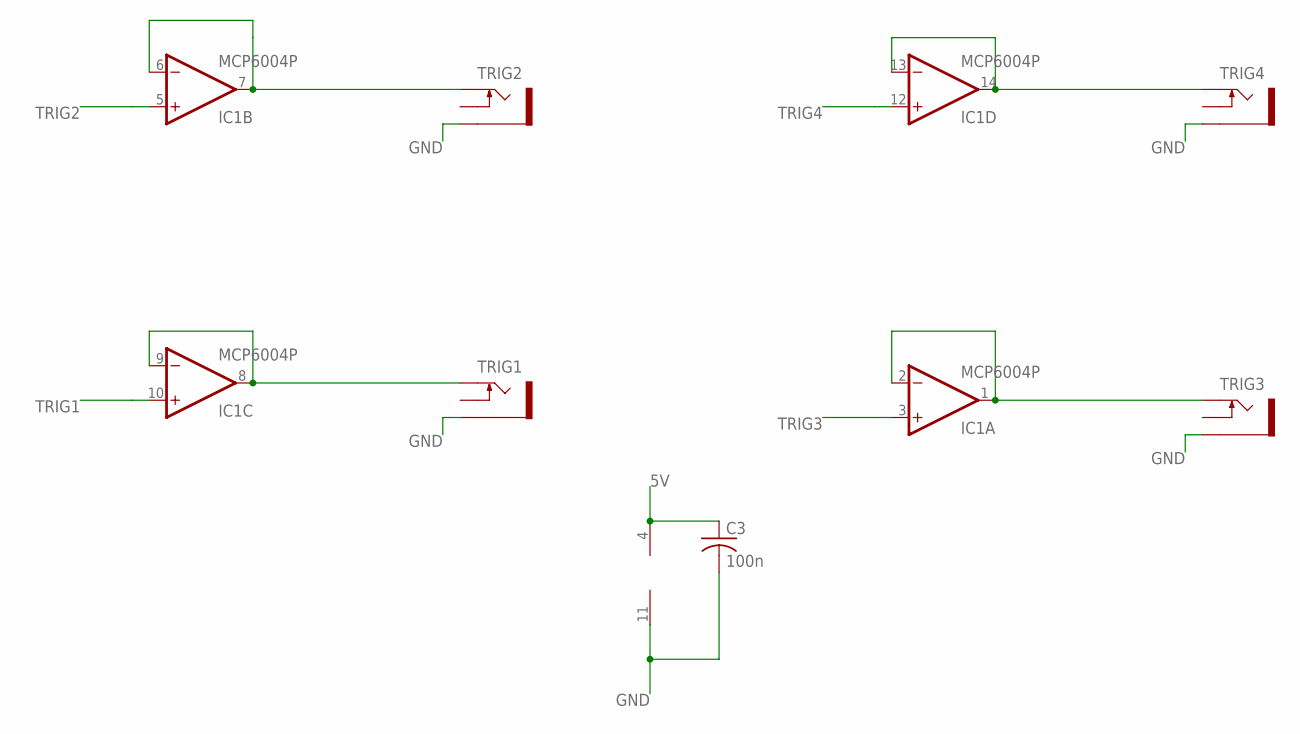
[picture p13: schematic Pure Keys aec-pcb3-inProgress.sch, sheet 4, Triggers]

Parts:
C3: 100n; C0805K
IC1: MCP6004P; DIL14
TRIG1, TRIG2, TRIG3, TRIG4: PJ302M

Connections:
5V: C3.1, IC1.4 (V+); also elsewhere on the board
GND: C3.2, IC1.11 (V-), TRIG1.GND (SLEEVE), TRIG2.GND (SLEEVE), TRIG3.GND (SLEEVE), TRIG4.GND (SLEEVE); also elsewhere on the board
unnamed: IC1.6 (-IN), IC1.7 (OUT), TRIG2.TIP
unnamed: IC1.8 (OUT), IC1.9 (-IN), TRIG1.TIP
unnamed: IC1.13 (-IN), IC1.14 (OUT), TRIG4.TIP
unnamed: IC1.1 (OUT), IC1.2 (-IN), TRIG3.TIP
TRIG1: IC1.10 (+IN); also elsewhere on the board
TRIG2: IC1.5 (+IN); also elsewhere on the board
TRIG3: IC1.3 (+IN); also elsewhere on the board
TRIG4: IC1.12 (+IN); also elsewhere on the board


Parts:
C5, C8, C11: 100n; C0805K
C6, C7: 10u; C0805K
CV1, CV2, CV3, CV4: PJ302M
IC5: MCP6004P; DIL14
U$1, U$2: MCP4922MCP4922-DIL14; DIL14

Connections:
3VREF: U$1.11 (VREFB), U$1.13 (VREFA), U$2.11 (VREFB), U$2.13 (VREFA); also elsewhere on the board
5V: C5.1, C6.1, C7.1, C8.1, C11.1, IC5.4 (V+), U$1.1 (VDD), U$1.9 (~SHDN), U$2.1 (VDD), U$2.9 (~SHDN); also elsewhere on the board
CS1: U$1.3 (~CS); also elsewhere on the board
CS2: U$2.3 (~CS); also elsewhere on the board
GND: C5.2, C6.2, C7.2, C8.2, C11.2, CV1.GND (SLEEVE), CV2.GND (SLEEVE), CV3.GND (SLEEVE), CV4.GND (SLEEVE), IC5.11 (V-), U$1.8 (~LDAC), U$1.12 (AVSS), U$2.8 (~LDAC), U$2.12 (AVSS); also elsewhere on the board
MOSI: U$1.5 (SDI), U$2.5 (SDI); also elsewhere on the board
unnamed: CV1.TIP, IC5.8 (OUT), IC5.9 (-IN)
unnamed: CV4.TIP, IC5.6 (-IN), IC5.7 (OUT)
unnamed: CV3.TIP, IC5.1 (OUT), IC5.2 (-IN)
unnamed: CV2.TIP, IC5.13 (-IN), IC5.14 (OUT)
SCK: U$1.4 (SCK), U$2.4 (SCK); also elsewhere on the board
VOUTA: IC5.10 (+IN), U$1.14 (VOUTA)
VOUTB: IC5.12 (+IN), U$1.10 (VOUTB)
VOUTC: IC5.3 (+IN), U$2.14 (VOUTA)
VOUTD: IC5.5 (+IN), U$2.10 (VOUTB)


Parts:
BUT1, BUT2: PB6149L-5; PB6149L
GLIDE1: rate; POT
R2, R56: 330R; R0805
R8, R9: 100K; R0805

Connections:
5V: GLIDE1.P$1 (1), R8.2, R9.2; also elsewhere on the board
BUT1: BUT1.3 (2), BUT1.4, R8.1; also elsewhere on the board
BUT2: BUT2.3 (2), BUT2.4, R9.1; also elsewhere on the board
BUTLED1: BUT1.A; also elsewhere on the board
BUTLED2: BUT2.A; also elsewhere on the board
GND: BUT1.1 (3), BUT1.2 (1), BUT2.1 (3), BUT2.2 (1), GLIDE1.P$3 (3), R2.1, R56.1; also elsewhere on the board
unnamed: BUT2.K (C), R2.2
unnamed: BUT1.K (C), R56.2
POT1: GLIDE1.P$2 (2); also elsewhere on the board


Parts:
CLK_IN: PJ302M
R5: 10K; R0805
R6: 100K; R0805
R7: 1M; R0805
T1: 2N3904; TRANSISTOR_SINGLE_N-TYPE

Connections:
5V: R5.2; also elsewhere on the board
CLK_IN: R5.1, T1.C; also elsewhere on the board
GND: CLK_IN.GND (SLEEVE), R7.1, T1.E; also elsewhere on the board
unnamed: R6.1, R7.2, T1.B
unnamed: CLK_IN.TIP, R6.2

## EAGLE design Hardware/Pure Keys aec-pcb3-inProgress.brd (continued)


Board: 2 copper layers, 99.0 x 98.7 mm, 61 parts (0 on the bottom side), 58 nets.

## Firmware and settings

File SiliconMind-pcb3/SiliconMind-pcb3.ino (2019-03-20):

#include "SPI.h"
#include <EEPROM.h>

#define MONO 1
#define SPLIT 2
#define POLY 3

#define NONE 0
#define PLAY 1
#define RECORD 2

const int MaxPoly = 4;
int SPLITKEY = 16;
const byte GateInInterrupt = 2;
boolean LedState = false;


int DACS[2] = {10, 10};
byte AIN[] = {A2, A3, A4};
int ButLED1 = 8;
int ButLED2 = 7;
int ButLED3 = 9;
int LEDS[3] = {8, 7, 9};

volatile int LedFlashCount1 = 0;
volatile int LedFlashCount2 = 0;
int But1 = 6;
int But2 = 7;
int But3 = 5;
boolean But1State = false;
boolean But2State = false;
boolean But3State = false;
int RecordMode = NONE;
int LowKeyOffset = 0;
int mode = MONO;
int CurrentPoly = 4;
int DAIN = A1;
int DBIN = A0;
float PortRate = 0.25; //Initial Portemantau rate
float Range = 1365.333; // (2^12/3)

/*
   Calculation is Range * (Octave + (float)Note / 12);
   So Range is steps per Octave
*/

int AssignedKeyPressed[MaxPoly + 1];
float CurrentOutValue[MaxPoly + 1];
int CurrentTarget[MaxPoly + 1];
boolean States[MaxPoly + 1];
boolean CurrentGates[MaxPoly + 1];
int ScannedKeys [MaxPoly];
int LastKeys[MaxPoly + 1];

byte Octave = -1;
byte Note = -1;
int outValue = 0;


int GateOut[MaxPoly] = {A5, 0, 1, 3};
const int MAXSEQ = 64;
volatile int SequenceNotes[MAXSEQ];
volatile int SequenceGates[MAXSEQ];
volatile int SequenceGateLength[MAXSEQ];
volatile int SequenceLength = 0;
volatile int CurrentSequenceNum = 0;
volatile int GateLengthPtr = 0;

const int MaxCurve = 250;
int fCurve[MaxCurve];
int PortPot = A6;
int GatePot = A7;
int GateLength = 0;



//gets the portamento rate
void getPortRate() {
  float Val = (float)(analogRead(PortPot) / 1024.0);
  Val = Val * Val * Val; //Create a cubic curve
  PortRate = (float)(Val) * 250;

  GateLength = analogRead(GatePot);

}

void setup() {

  for (byte A = 4; A < 7; A++) {
    pinMode(A, OUTPUT);
  }

  for (byte A = 0; A < 3; A++) {
    pinMode(AIN[A], OUTPUT);
  }

  for (int i = 0; i < MaxPoly; i++) {
    pinMode(GateOut[i], OUTPUT);
    digitalWrite(GateOut[i], false);

    States[i] = false;
    AssignedKeyPressed[i] = -1;
    CurrentOutValue[i] = 0;
    CurrentTarget[i] = 0;
    CurrentGates[i] = false;
  }
  pinMode(DACS[0], OUTPUT);
  pinMode(DACS[1], OUTPUT);
  digitalWrite(DACS[0], HIGH);
  digitalWrite(DACS[1], HIGH);
  if (mode == MONO)
    CurrentPoly = 1;
  else if (mode == SPLIT)
    CurrentPoly = 2;
  else if (mode == POLY)
    CurrentPoly = MaxPoly;
  pinMode(ButLED1, OUTPUT);
  pinMode(ButLED2, OUTPUT);
  pinMode(ButLED3, OUTPUT);
  digitalWrite(ButLED1, HIGH);
  digitalWrite(ButLED2, HIGH);
  digitalWrite(ButLED3, HIGH);
  pinMode(DAIN, INPUT);
  pinMode(DBIN, INPUT);
  SPI.begin();
  SPI.setBitOrder(MSBFIRST);
  delay(500);
  double scale = 4095.0 / pow(0.1, (-1.0 / 2.0));
  int i = 0;
  for (double f = 0.1; f < (MaxCurve / 10.0); f = f + 0.1) {
    double ans = scale * pow(f, (-1.0 / 2.0));
    fCurve[i] = (int)ans;
    i++;
  }
  digitalWrite(ButLED1, LOW);
  digitalWrite(ButLED2, LOW);
  digitalWrite(ButLED3, LOW);
  ReadEEProm();
  attachInterrupt(digitalPinToInterrupt(GateInInterrupt), HandleClock, FALLING);
}

volatile int hKey ;
volatile int hOctave;
volatile int hNote;
volatile int houtValue;
void HandleClock() {

  if (RecordMode != NONE) {
    if (RecordMode == PLAY) {

      LedFlashCount1 = 1;

      hKey = SequenceNotes[CurrentSequenceNum];
      hOctave = (byte)(hKey / 12);
      hNote = (byte)(hKey % 12);
      houtValue = (int)(Range * (hOctave + (float)hNote / 12)) + LowKeyOffset;
      digitalWrite(GateOut[0], SequenceGates[CurrentSequenceNum]);
      mcpWrite(houtValue, 0, 0); //Send the value to the  DAC
      CurrentSequenceNum++;
      if (CurrentSequenceNum >= SequenceLength) {
        CurrentSequenceNum = 0;
      }
      return;
    } else {
      
      LedFlashCount2 = 1;
      SequenceNotes[CurrentSequenceNum] = AssignedKeyPressed[0];
      SequenceGates[CurrentSequenceNum] = CurrentGates[0];
      SequenceLength = CurrentSequenceNum + 1;
      CurrentSequenceNum++;
      if (CurrentSequenceNum > MAXSEQ) {
        CurrentSequenceNum = MAXSEQ;
      }
    }
  }
}


void FlashLeds() {
  if (LedFlashCount1 != 0) {
    digitalWrite(ButLED1, HIGH);
    LedFlashCount1++;
    if (LedFlashCount1 > GateLength)
      LedFlashCount1 = 0;
  } else {
    digitalWrite(ButLED1, LOW);
    if (RecordMode == PLAY) {
      digitalWrite(GateOut[0], false); //Take the gate into a low state.
    }
  }

}

void getRecordMode() {
  boolean State2 = GetSwitchState(But2);
  boolean State3 = GetSwitchState(But3);
  if ((But2State == false) && (State2 == true)) {
    if (RecordMode != PLAY) {
      RecordMode = PLAY;
      digitalWrite(ButLED2, HIGH);
      But2State = false; //true
      CurrentSequenceNum = 0;
    } else {
      RecordMode = NONE;
      digitalWrite(ButLED2, false);
    }
  }
  if ((But3State == false) && (State3 == true)) {
    if (RecordMode != RECORD) {
      digitalWrite(ButLED3, HIGH);
      RecordMode = RECORD;
      CurrentSequenceNum = 0;
      But3State = false; //true
    } else {
      RecordMode = NONE;
      digitalWrite(ButLED3, false);
      SaveEEProm();
    }
  }
}

void SetPolyMode() {
  boolean State = GetSwitchState(But1);
  if ((But1State == false) && (State == true)) {
    //Change the mode
    mode++;
    if (mode > POLY) {
      mode = MONO;
    }
    flash(mode, ButLED1);
    if (mode == MONO)
      CurrentPoly = 1;
    else if (mode == SPLIT)
      CurrentPoly = 2;
    else if (mode == POLY)
      CurrentPoly = MaxPoly;
  }
  But1State = State;
}



void loop() {
  FlashLeds();
  SetPolyMode();
  getPortRate();
  getRecordMode();
  ScanKeyboard();
  if (mode == MONO) {
    AssignMonoVoices();
  }
  if (mode == SPLIT) {
    AssignSplitVoices();
  }
  if (mode == POLY) {
    AssignVoices();
  }
  WriteNotesOut();
}



void AssignMonoVoices() {
  //Find notes this time the same as last and keep a list
  //Which KeyPressed location are they
  //for each unassigned note find a location for it.
  int CurrentFinger = 0;

  int Key = -1;
  for (int i = 0; i < CurrentPoly; i++) { //Assign voices
    Key = ScannedKeys[i];
    //if (Key != -1) {
    States[CurrentFinger] = true;
    AssignedKeyPressed[CurrentFinger] = Key;       //Record this Key
    CurrentFinger++;
    //}
  }
}

void AssignSplitVoices() {
  //Find notes this time the same as last and keep a list
  //Which KeyPressed location are they
  //for each unassigned note find a location for it.
  int Key = -1;
  if (RecordMode != PLAY) {
    AssignedKeyPressed[0] = -1;
  }
  AssignedKeyPressed[1] = -1;
  for (int i = 0; i < CurrentPoly; i++) { //Assign voices
    Key = ScannedKeys[i];
    if ((Key <= SPLITKEY) && (Key >= 0)) {
      AssignedKeyPressed[0] = Key;       //Record this Key

    }
    if (Key > SPLITKEY) {
      AssignedKeyPressed[1] = Key;       //Record this Key
    }
  }
}

//This is for polyphonic mode

void AssignVoices() {
  int newKeyPressed[] = { -1, -1, -1, -1};
  int CurrentFinger = -1;
  //Test out last keys to current one

  int Key = -1;
  //Find notes this time the same as last and keep a list
  int KeptFingers[] = { -1, -1, -1, -1};
  int newKeys[] = { -1, -1, -1, -1};

  FindKeptFingers(KeptFingers);

  FindNewNotes(newKeys);
  //report(KeptFingers,newKeys);

  SetKeptKeys(KeptFingers, newKeyPressed);
  SetNewKeys(newKeys, newKeyPressed);

  for (int k = 0; k < 4; k++) {
    AssignedKeyPressed[k] = newKeyPressed[k];
    if (newKeyPressed[k] != -1)
      States[k] = true;
  }

}


void SetNewKeys(int newKeys[], int newKeyPressed[]) {
  for (int k = 0; k < 4; k++) {
    if (newKeys[k] != -1) {
      for (int j = 0; j < 4; j++) { //find a free slot
        if (newKeyPressed[j] == -1) {
          newKeyPressed[j] = ScannedKeys[newKeys[k]];
          break;
        }
      }
    }
  }
}

void SetKeptKeys(int KeptFingers[], int newKeyPressed[]) {
  for (int k = 0; k < 4; k++) {
    if (KeptFingers[k] != -1) {
      newKeyPressed[KeptFingers[k]] = AssignedKeyPressed[KeptFingers[k]];
    }
  }
}


void FindNewNotes(int newKeys[]) {
  //Find new notes
  int ptrNew = 0;
  int Key = -1;
  for (int i = 0; i < CurrentPoly; i++) {
    Key = ScannedKeys[i];
    if (Key != -1) {
      boolean Found = false;
      for (int j = 0; j < CurrentPoly; j++) {
        if (Key == AssignedKeyPressed[j]) {
          Found = true;
          break; //Go onto next key
        }

      }
      if (Found == false) {
        //System.out.println(ptrKept + "   Key " + Key);

        newKeys[ptrNew] = i;

        ptrNew++;


      }
    }
  }
}

void FindKeptFingers(int KeptFingers[]) {
  int Key = -1;
  int ptrKept = 0;//Find notes this time the same as last and keep a list
  for (int i = 0; i < CurrentPoly; i++) {
    Key = AssignedKeyPressed[i];
    for (int j = 0; j < CurrentPoly; j++) {
      if ((Key == ScannedKeys[j]) && (ScannedKeys[j] != -1)) {
        KeptFingers[ptrKept] = i;
        ptrKept++;
        break; //Go onto next key
      }
    }
  }
}

boolean in1 = true;
boolean in2 = true;

byte sum = 0;
byte last = 0;
int VCount = 0;
boolean VelWritten = false;

void ScanKeyboard() {
  for (int i = 0; i < MaxPoly; i++) {  //reset scan

    States[i] = false;
    ScannedKeys[i] = -1;
  }
  int Key = -1;
  for (int i = 0; i < 8; i++) { //scan keyboard and order them low to high
    WriteAdd(i);
    for (int j = 0; j < 5; j++) {

      WriteInAdd(j);
      in1 = digitalRead(DAIN);
      in2 = digitalRead(DBIN);

      if ((in1 == true) or (in2 == true))   {
        Key = (8 * j) + i;

        for (int l = 0; l < MaxPoly; l++) {//This is an sort routine in case the notes do not come in order
          if (Key > ScannedKeys[l]) {
            if (ScannedKeys[l] == -1) {
              ScannedKeys[l] = Key;
              l = MaxPoly;
            }
          } else {
            //Insert it by moving everything up one
            for (int m = (MaxPoly - 2); m >= l; m--) {
              ScannedKeys[m + 1] = ScannedKeys[m];
            }
            ScannedKeys[l] = Key;
            l = MaxPoly;
          }

        }
      }
    }

  }
}



void WriteNotesOut() {

  int CurrentFinger = 0;
  int Key = -1;
  int PlayOffset = 0;
  int MaxLoop = CurrentPoly;
  if (RecordMode == PLAY) {//step over the sequenced note.
    PlayOffset = 1;
    MaxLoop = CurrentPoly + PlayOffset;
    if (MaxLoop > MaxPoly)
      MaxLoop = MaxPoly;
  }

  for (int i = 0; i < MaxLoop; i++) { //Write gate and voltage
    CurrentFinger = i;
    Key = AssignedKeyPressed[CurrentFinger];
    if (Key != -1) {
      LastKeys[CurrentFinger] = AssignedKeyPressed[CurrentFinger];
      Octave = (byte)(Key / 12);
      Note = (byte)(Key % 12);
      outValue = (int)(Range * (Octave + (float)Note / 12));
      digitalWrite(ButLED1, HIGH);
      /* Most of this deals with Portamento   */
      CurrentTarget[CurrentFinger] = outValue;
      int delta = outValue - CurrentOutValue[CurrentFinger];
      int Sign = 1;
      if (delta < 0)
        Sign = -1;
      CurrentOutValue[CurrentFinger] = CurrentOutValue[CurrentFinger] + Sign * PortRate;
      if (Sign > 0) {
        if (CurrentOutValue[CurrentFinger] >= CurrentTarget[CurrentFinger])
          CurrentOutValue[CurrentFinger] = CurrentTarget[CurrentFinger];
      }
      else {
        if (CurrentOutValue[CurrentFinger] <= CurrentTarget[CurrentFinger])
          CurrentOutValue[CurrentFinger] = CurrentTarget[CurrentFinger];
      }
      if ( mode != SPLIT) {

        mcpWrite(CurrentOutValue[CurrentFinger], (CurrentFinger + PlayOffset) / 2, (CurrentFinger + PlayOffset) & 0x01); //Send the value to the  DAC
        digitalWrite(GateOut[CurrentFinger + PlayOffset], true);
        CurrentGates[CurrentFinger + PlayOffset] = true;
        //in Mono mode, can we write to the other notes to ?
        //if ( mode == MONO) {
        //   mcpWrite(CurrentOutValue[CurrentFinger],0,1);
        //    mcpWrite(CurrentOutValue[CurrentFinger],1,0);
        //     mcpWrite(CurrentOutValue[CurrentFinger],1,1);
        //}
      } else {

        if (Key <= SPLITKEY) {
          LowKeyOffset = outValue;
          if (RecordMode != PLAY) {
            digitalWrite(GateOut[0], true);
            mcpWrite(outValue, 0, 0); //Send the value to the  Out 0
          } //We are going to send the value to out 4 as well so the base note is available as well as a played note
          mcpWrite(outValue, 1, 1); //Send the value to the  Out 4

        } else {
          digitalWrite(GateOut[1], true);
          mcpWrite(CurrentOutValue[CurrentFinger], 0, 1); //Send the value to the  Out 1
        }

      }

    }

    else {
      Key = LastKeys[CurrentFinger];
      CurrentGates[CurrentFinger + PlayOffset] = false;
      digitalWrite(ButLED1, LOW);
      if ( mode != SPLIT) {
        digitalWrite(GateOut[CurrentFinger + PlayOffset], false);

      } else {
        if ((Key <= SPLITKEY) && (Key >= 0)) {
          if (RecordMode != PLAY) {
            digitalWrite(GateOut[0], false);
          }
        }
        if ((Key > SPLITKEY) && (Key >= 0)) {
          digitalWrite(GateOut[1], false);
        }

        LastKeys[CurrentFinger] = -1;
      }
    }
  }
}

//Function for writing value to DAC. 0 = Off 4095 = Full on.

void mcpWrite(int value, int DAC, int Channel) {
  //set top 4 bits of value integer to data variable
  if (DAC == 0)
    digitalWrite(DACS[0], LOW);
  else
    digitalWrite(DACS[0], HIGH);
  byte data = value >> 8;
  data = data & B00001111;
  if (Channel == 0)
    data = data | B00110000; //DACA Bit 15 Low
  else
    data = data | B10110000; //DACB Bit 15 High

  cli(); //Disable Interupts

  SPI.transfer(data);
  data = value;
  SPI.transfer(data);
  // Set digital pin DACCS HIGH
  // Set digital pin DACCS HIGH

  sei();
  if (DAC == 0)
    digitalWrite(DACS[0], HIGH);
  else
    digitalWrite(DACS[0], LOW);

}

void WriteLED(byte address) {
  for (byte A = 0; A < 3; A++) {
    digitalWrite(LEDS[A], (boolean)(address & 0x01));
    address >>= 1;

  }
}

void WriteInAdd(byte address) {
  for (byte A = 0; A < 3; A++) {
    digitalWrite(AIN[A], (boolean)(address & 0x01));
    address >>= 1;

  }
}

void WriteAdd(byte address) {
  for (byte A = 4; A < 7; A++) {
    digitalWrite(A, (boolean)(address & 0x01));
    address >>= 1;

  }
}

/* debug code */
void flash(int count, int Button) {
  for (int i = 0; i < count; i++) {
    digitalWrite(Button, HIGH);
    delay(200);
    digitalWrite(Button, LOW);
    delay(200);

  }
}

boolean GetSwitchState(int Switch) {
  WriteInAdd(Switch);
  if (digitalRead(DAIN) == false) {
    return true;
  }
  return false;

}

struct SaveStruct {
  int SequenceNotes[64];
  int SequenceGates[64];
  int SequenceLength = 0;
};

int eeAddress = 0;
SaveStruct SaveNotes ;

void SaveEEProm() {
  for (int i = 0; i < 64; i++) {
    SaveNotes.SequenceNotes[i] = SequenceNotes[i];
    SaveNotes.SequenceGates[i] = SequenceGates[i];

  }
  SaveNotes.SequenceLength = SequenceLength;
  EEPROM.put(eeAddress, SaveNotes);

}

void ReadEEProm() {
  EEPROM.get(eeAddress, SaveNotes);
  for (int i = 0; i < 64; i++) {
    SequenceNotes[i] = SaveNotes.SequenceNotes[i];
    SequenceGates[i] = SaveNotes.SequenceGates[i];

  }
  SequenceLength = SaveNotes.SequenceLength;
}

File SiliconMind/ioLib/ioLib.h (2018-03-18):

#include "SPI.h"

int DACS[2] = {9,10};
int ENOUT=7;
int ENIN=A7;
int DAOUT=1;
int DBOUT=0;
int DAIN=A2;
int DBIN=A3;
int AOUT[] = {4, 5, 6};
int AIN[]={A4,A5,A6};

int BUTLED1=5;
int BUTLED2=6;

int BUT1=6;
int BUT2=7;

void setup() {
  // put your setup code here, to run once:
  SPI.begin();
  SPI.setBitOrder(MSBFIRST);
}

void loop() {
  // put your main code here, to run repeatedly:

}

void WriteOutAdd(byte address) {
    address=address-1;
  for (byte A = 0; A < 3; A++) {
    digitalWrite(AOUT[A], (boolean)(address & 0x01));
    address >>= 1;

  }

}

void WriteInAdd(byte address) {
    address=address-1;
  for (byte A = 0; A < 3; A++) {
    digitalWrite(AIN[A], (boolean)(address & 0x01));
    address >>= 1;

  }

}


boolean digitalReadPort(int channel, int port){
  boolean state=false;
   WriteInAdd(port);
  if (channel=DAIN){   
      digitalWrite(ENIN, true);
      if (digitalRead(DAIN)==true)
         state=true;
       digitalWrite(ENIN, false);
  }else{    
      digitalWrite(ENIN, true);
      if (digitalRead(DBIN)==true)
         state=true;
       digitalWrite(ENIN, false);
    
  }
  return state;
}


void mcpWrite(int value, int DAC,int Channel) {
  //CS

  digitalWrite(DACS[DAC], LOW);
  //DAC1 write
  //set top 4 bits of value integer to data variable
  byte data = value >> 8;
  data = data & B00001111;
  if (Channel==0)
     data = data | B00110000; //DACA Bit 15 Low
  else
     data = data | B10110000; //DACB Bit 15 High
  SPI.transfer(data);
  data = value;
  SPI.transfer(data);
  // Set digital pin DACCS HIGH
  digitalWrite(DACS[DAC], HIGH);



}

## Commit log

2017-10-28 added arduino code
2017-11-02 First hardware layout
    [SiliconMind.sch]
2017-11-02 Board Template added
    [SiliconMind.brd]
2017-11-03 added micro match connector
    [SiliconMind.brd, SiliconMind.sch]
2017-11-03 Changed TL074 to TTL
    [SiliconMind.brd, SiliconMind.sch]
2017-11-09 added IDC connector
    [SiliconMind.brd, SiliconMind.sch]
2017-11-14 removed voltage table
2017-11-22 temp push while sort is fixed
    [SiliconMind.ino]
2017-11-22 temp push while sort is fixed 2
    [SiliconMind.ino]
2018-02-05 My Board
    [Pure Keys aec.brd, Pure Keys aec.sch]
2018-02-05 removed old board
    [SiliconMind.brd, SiliconMind.sch]
2018-02-05 Slight update
    [Pure Keys aec.brd, Pure Keys aec.sch]
2018-02-06 Changed MUX/DEMUX connections and removed one POT
    [Pure Keys aec.brd, Pure Keys aec.sch]
2018-02-06 added back plane
    [Pure Keys aec.brd]
2018-03-04 added pcb1 borad and schematic THis borad has a TL072 on it that is NOT needed. Left over form clock in
    [Pure Keys aec-pcb1.brd, Pure Keys aec-pcb1.sch]
2018-03-04 added in progress board and change log
    [Pure Keys aec-pcb2-inProgress.brd, Pure Keys aec-pcb2-inProgress.sch]
2018-03-07 updated in progress board added text layer text added classes for power rerouted
    [Pure Keys aec-pcb2-inProgress.brd, Pure Keys aec-pcb2-inProgress.sch]
2018-03-07 Added dxf file for tcream
    [Pure Keys aec-pcb1.dxf]
2018-03-13 updated board and tests
    [Pure Keys aec-pcb2-inProgress.brd, Pure Keys aec-pcb2-inProgress.sch]
2018-03-13 added tests for AEC board
2018-03-15 changed 74238 for 74138
    [Pure Keys aec-pcb1.brd, Pure Keys aec-pcb1.sch, Pure Keys aec-pcb2-inProgress.brd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]
2018-03-16 updated switches on in progress
    [Pure Keys aec-pcb2-inProgress.brd, Pure Keys aec-pcb2-inProgress.sch]
2018-03-19 updated code to PCB 1
2018-03-19 Updated routing on in-progress board to make room for 1K pull downs
    [Pure Keys aec-pcb2-inProgress.brd, Pure Keys aec-pcb2-inProgress.sch]
2018-03-19 Added tests to GMSN! board
2018-03-20 changed in progress board
    [Pure Keys aec-pcb2-inProgress.brd, Pure Keys aec-pcb2-inProgress.sch]
2018-03-21 changed pcb2-in-progress with ne layout of MK resistors
    [Pure Keys aec-pcb2-inProgress.brd, Pure Keys aec-pcb2-inProgress.sch]
2018-03-21 added PCB 2
    [Pure Keys aec-pcb2.brd, Pure Keys aec-pcb2.sch]
2018-03-27 Added pcb3-inProgress
    [Pure Keys aec-pcb3-inProgress.brd, Pure Keys aec-pcb3-inProgress.sch]
2018-03-29 adding part numbers to attributes
    [Pure Keys aec-pcb3-inProgress.brd, Pure Keys aec-pcb3-inProgress.sch]
2018-03-29 routing on pcb-3-inprogress
    [Pure Keys aec-pcb3-inProgress.brd, Pure Keys aec-pcb3-inProgress.sch]
2018-03-29 Updated vesion message
    [Pure Keys aec-pcb3-inProgress.brd]
2018-04-09 Poly mode switch working
2018-04-12 Added record switch fucntionality (not recording)
2018-04-16 Save to Eprom works, splt mode broken, crashes if you play keyboard and sequence at the same time
    [SiliconMind.ino]
2018-04-17 Save to Eprom works, splt mode broken
    [SiliconMind.ino]
2018-04-24 First Attempt at fixing poly mode to stick keys
    [SiliconMind.ino]
2018-07-26 Added Pcb3 SMD
    [Pure Keys aec-pcb3-smd-inProgress.brd, Pure Keys aec-pcb3-smd-inProgress.sch]
2018-07-26 changed cs select
    [Pure Keys aec-pcb3-smd-inProgress.brd, Pure Keys aec-pcb3-smd-inProgress.sch]
2018-07-27 New Board Shape and layout
    [Pure Keys aec-pcb3-smd-inProgress.brd]
2018-07-27 THinner board
    [Pure Keys aec-pcb3-smd-inProgress.brd]
2018-07-28 Removed voltage class for SMD
    [Pure Keys aec-pcb3-smd-inProgress.brd, Pure Keys aec-pcb3-smd-inProgress.sch]
2018-07-28 Moved text on rear
    [Pure Keys aec-pcb3-smd-inProgress.brd]
2018-07-29 Replaced Sockets with vertical type
    [Pure Keys aec-pcb3-smd-inProgress.brd, Pure Keys aec-pcb3-smd-inProgress.sch]
2018-07-29 Added a SMD with Vertical Pots
    [Pure Keys aec-pcb3-smd-Vertical-inProgress.brd, Pure Keys aec-pcb3-smd-Vertical-inProgress.sch]
2018-07-29 ground plane
    [Pure Keys aec-pcb3-smd-Vertical-inProgress.brd]
2018-07-30 added Pcb3 in manufacture
    [Pure Keys aec-pcb3.brd, Pure Keys aec-pcb3.sch]
2018-08-01 change to pcb3 brd
    [Pure Keys aec-pcb3.brd]
2018-08-01 Added RS Parts to Semicnductors
    [Pure Keys aec-pcb3.brd, Pure Keys aec-pcb3.sch]
2018-08-01 Added excel parts list
    [Pure Keys aec-pcb3-BOM.xlsx]
2018-08-01 Fixed mistake in attribute of invertor
    [Pure Keys aec-pcb3-BOM.xlsx, Pure Keys aec-pcb3.brd, Pure Keys aec-pcb3.sch]
2018-08-01 Split mode portamanto fix
    [SiliconMind.ino]
2018-09-24 added BOM
    [Pure Keys aec-pcb3.xlsx]
2019-01-29 added tests for PCB3
2019-03-13 added PCB 4
    [Pure Keys aec-pcb4-inprogress.brd, Pure Keys aec-pcb4-inprogress.sch]
2019-03-13 updated velocity test
2019-03-13 added Switch test
2019-03-15 tried new board layout
    [Pure Keys aec-pcb4-inprogress.brd, Pure Keys aec-pcb4-inprogress.sch]
2019-03-18 Software for PCB3
2019-03-20 Moved pcb3 test to pcb3
2019-03-20 Play and record buttons (Need debouncing)
2019-03-20 Fixed Play LED (Need debouncing)
    [SiliconMind-pcb3.ino]

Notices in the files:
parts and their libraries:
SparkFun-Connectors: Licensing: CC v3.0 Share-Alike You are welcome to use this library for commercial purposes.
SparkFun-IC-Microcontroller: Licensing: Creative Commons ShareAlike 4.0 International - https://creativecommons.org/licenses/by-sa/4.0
